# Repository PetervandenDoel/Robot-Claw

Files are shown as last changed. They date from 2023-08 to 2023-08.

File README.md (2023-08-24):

# Robot-Claw

The project demo date was not filmed, the video included is us testing its functionality before the claw was fully assembled. A video of the full project will be uploaded once we can get some of the teammates back together to film a proper demo.  
https://drive.google.com/file/d/1z_p-viNf-aqcb_K7y_1ZdQ1qlZZi11r3/view?usp=sharing

ELEC 391 Claw

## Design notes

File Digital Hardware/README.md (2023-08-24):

The PCB for all the digital hardware. Below the images is an explanation of design choices.











**Decoder and MUX saving GPIOs:** The motor decoder chip that was chosen counts encoder pulses and returns them as a 32 bit value. The decoder requires a clock which is what the crystal oscillator on the PCB is for. The data is accessed across 8 pins with a 2 bit internal multiplexer to iterate through each set of eight bits to retrieve the 32 bit value. With 8 data pins and four pins for interfacing with it, the decoder requires a total of 12 GPIO pins to function. In order to save on GPIO pins a three bit multiplexer was used which complicated the firmware's get_position() routine, but reduced the number of data pins down from 8 to 3 select pins and 1 data input for a total of only 8 GPIO pins needed to read the motor's position.  

**Headers:** This is really the key theme of this PCB so the header types will be discussed individually. All of the all the headers used in this PCB were arduino female headers with clips inside of them similar to this screenshot.



**Level shifter headers:** the headers labelled MUXLS, MISCLS, DECLS, and ANLS are for adafruit level shifters to shift the signals between the 3.3V ESP32 and the 5V multiplexer, ultrasound sensor, decoder, and analog PCB interface respectively. While the ESP 32 can tolerate 5 volts as an input, it cannot output 3.3 volts and it is simply best practice to level shift either way. It proved useful to keep the level shifters and headers because they could be removed to perform tests with breadboard prototypes or use the headers as debug pins and placed back in whenever we wanted. At one point when we did not have an ESP32 available, we simply shorted all of the level shifter headers together with jumpers and ran the board using a 5V Arduino mega.

**ESP32 Headers:** The ESP 32 dev board could be removed and plug back into headers as opposed to having it soldered into the PCB. The ESP 32 would actually refuse to have code flashed on to it when it was plugged into the PCB or our breadboard prototype(probably something to do with where TX and RX pins are connected) so the arduino style headers proved essential. The second set of debug headers directly adjacent also proved to be extremely useful when trying to identify issues with noise and multiplexer signals

There are two other headers one to connect the ultrasonic distance sensor module to the esp, and one that connects to the analog PCB to control the motor and act as a 5V power supply for the digital hardware.

**Silkscreens:** A lot of time was put in to maximally label every pin on every header without violating the PCB manufacturer's silkscreen design rules. Different labels were made different sizes based on the readability of the individual characters at those sizes and thicknesses to preserve space and maximize the amount of labels. These ended up being invaluable for debugging and allowed us, at one point, to use an Arduino mega instead of an ESP32 and connect all the GPIOs to the right pins without much issue.

**Power planes:** A 5V(red) and GND(blue) plane were implemented with the aim of reducing noise, this should have been done differently and will be discussed among potential improvements 

**potential improvements**

**Decoder crosstalk(main issue):** 
**How do we know the issue is crosstalk?** The motor's position value that the ESP32 acquired from the decoder+MUX was quite prone to spiking and some digital low pass filtering had to be implemented to tell the PID controller to ignore junk data. If the encoder signals themselves were having problems, the huge spikes would have been stored in the decoder's internal register, but these spikes were transient and the values always settled back to a reasonable one which suggests bits being flipped because of crosstalk on the lines between the decoder and the multiplexer. 

**Why is there crosstalk?** The traces connecting the decoder and multiplexer are so close that some of them don't even have any ground plane separating them to absorb EMI(picture below). In the getByte() function, the select signals of the multiplexer change around once per microsecond so it's unsurprising that high frequency signals can flip bits on adjacent traces that aren't even shielded from one another, they should have been spaced out more.



**Unused routing space:** A lot of traces are routed very close together despite the fact that there is actually a lot of space on the board that routing could be done through.

**Power planes:** Since this is not a high power circuit, it doesn't make too much sense to have 5V and GND power planes. Instead, it would make more sense to have a ground plane on each layer for noise reduction. 

**Crystal is too large, literally:** A very large thru-hole crystal oscillator was chosen for the motor decoder. Seeing how the crystal just clocks digital hardware inside of the decoder, frequency stability and impedance characteristics aren't very important. It would have been wise to compromise on other characteristics in order to get a smaller crystal. 

**Aesthetics:**
**Non-symmetrical screw holes:** Our professor actually criticized us for this funnily enough. There are two holes for screws on the top of the PCB but not the bottom and the asymmetry is kind of weird.
**Sporadic name placement:** Our names are placed in random spots all over the PCB wherever we could fit them, we don't have one nice little corner that we put all of them in; it could look a lot better.

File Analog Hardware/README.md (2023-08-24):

Pictures have been included and below the pictures there is an explanation of design choices










**Design choices:**

**Power planes:** a ground(blue) and 12 Volt(red) plane were used in order to minimize the impedance between the power supply and components

**power supply** 12V barrel jack will normally supply power, but there is also a 12V GND header which allows for other power supplies to be used besides just the barrel Jack. The 5V GND header proved useful for providing only digital power when trying to debug our design without actually driving the motor and causing our claw to move; it allowed to test our state machine, decoder, and control system while moving the claw by hand.

**Motor Traces:** the PCB traces supplying the motor with power were made very thick in order to minimize resistance

**Headers:** There are two sets of headers, one to connect the analog PCB to the digital PCB and the other one to connect the analog PCB to the motor. for both of them an additional debug header was provided. The motor debug header proved useful for debugging because it allowed us to probe the motor's encoder pulses and power signals. A pure 5V GND and 12V GND header were also included to allow us to supply power to other devices, serve as an additional power source besides the barrel Jack, and hotswap power supply regulation capacitors to see what worked for us.

**PCB shape:** the PCB's edges were clipped in order to avoid having 90 degree edges on our power planes. The PCB was also designed to be compact and small to fit within an internal compartment of the claw

**Motor driver:** A premade H bridge IC with sufficent rated current simplifies the process of driving the motor and allows us to not have to worry about any of the complex timing that goes into designing an H bridge driver to avoid shorts 

**Motor** a JGA25 brshed DC motor was chosen with a built in decoder and 42 to one gearbox to allow for sufficient torque and for the motor shaft to be directly coupled to our claw mechanism without needing to construct a gearbox ourselves

**room for improvement** 

**too much room for caps** the Altium footprints chosen for our power supply regulation capacitors are way too big for what we actually used, some smaller ones would have helped us save space

**analog to digital PCB header** the plastic clip to connect the analog PCB to the digital PCB never ended up being used. It would have been better to have two identical thru-hole headers to allow for debugging the signals that would go from the analog to digital board.

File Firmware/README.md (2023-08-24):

ELEC 391 state

The claw operates as a state machine that will open until a limit switch is hit in order to zero its position, then using an ultrasonic distance sensor it will close when it detects that it is close enough to the ground to pick up an object and once the user carries the claw upwards and then brings it back down above another surface it will drop the object. The claw's position is controlled by driving a motor at a given PWM frequency and direction using a PID control loop triggered at a known control frequency through an interrupt service routine. 

Some firmware design choices

**Filtering: Line 474:** due to bit errors in the signals read from the multiplexers, there are sometimes large spikes in the determined position value. A simple low pass filter is implemented where if the current error differs from the previous error by too large of a number, the previous error is returned. 

**Missed Echos: Line 344:** ultrasound sensor values that are too high are also filtered out because they are assumed to be due to missed echoes

**State machine hysteresis: in every state transition:** I have heard this technique referred to as hysteresis before in some contexts but I'm not sure if that's a proper term. The ultrasonic sensor distance boundaries for transitions between the claw's different states are placed sufficiently far apart enough that rapid transitions when the user has the claw around the border between two states will never happen. 

**get_position modularity: line 113 to 293:** the motor decoder chip outputs a 32 bit value in 8 bit increments determined by select signals fed into the internal multiplexer. Another external multiplexer is used in order to reduce the number of GPIO pins that need to be used to read from the decoder from 8 down to 5. A helper function called getByte was created as a routine to extract one byte of data from the 8 decoder pins by iterating through all the select signals on the external multiplexer. get_position calls getByte 4 times, once for every select signal fed to the decoders internal multiplexer so the total 32 bit value can be acquired

**PID nonlinearities:** due to problems with the static friction of the joints, some nonlinearities were introduced into the PID controller in order to help it behave better. The three PID nonlinearities are listed below and are justified.

**Duty cycle boundries: line 499:** a hard upper and lower limit are placed on the allowable motor driver duty cycles so if the control signal exceeds a certain amount or falls below a certain amount it will be pulled back to within a certain range. Setting a lower bound allows the claw to continue moving as opposed to getting stuck due to static friction when the control signal reduces as the desired position is approached. An upper bound is set because the heavy claws will gain too much momentum if the control signal is allowed to be too high. 

**"settled" condition: line 481:** once the error drops below a certain point the PID loop is told to stop and consider itself to have settled on the correct position as opposed to allowing slight integral error to continue building causing the claw to sharply bounce back and forth. The reason why it sharply bounces back and forth instead of oscillating is because as the control signal slowly builds, the motor slowly starts outputting enough torque to the point where once static friction is overcome the claw will jerk a little bit and then stop again.

**integral error reset:** on every state transition: the integral term for the PID controller is reset every single time a state transition occurs and the new desired position is set. Because the claw moves quite slowly a lot of integral air is build up in the time it takes for the claw to close or open as it does in response to state transitions. This large build of integral error ended up being quite problematic so it was reset to 0 on every state transition

**controlling LED's duty cycle without interrupts: line 442:** in order to avoid any complexities with prioritizing interrupts a single interrupt is used for the PID control loop and controlling the duty cycle of a blinking LED to represent state. Since the LED blinks every 1s the PID loop runs every 0.1s, and the LED duty cycles for the different states differ by increments of 0.1s, an LED counter variable is incremented and modulo operations are used within each state to determine whether the LED should be on or off and this achieves the controlled duty cycle cycle blinking behavior.

**Room for improvement** 

**removing overley cautious multiplexer settle delays** the highly conservative control frequency of 10 Hertz was chosen based on code that gave multiplexer signals excessive amounts of time to settle when acquiring motor position from the decoder. The get_position function has multiple 25ms delays and shortening these delays by orders of magnitude would probably not cause problems and allow for a much faster control frequency and better PID performance.

**Multiple interrupt management**  Since turning an LED on or off is very quick, controlling the LED's duty cycle using another ISR would probably not interrupt our PID controller very much and would have allowed us to have any control frequency we want and any LED duty cycle we want without having to tie the two quantities together in order to use the same interrupt for two tasks.

**separate position acquisition process to allow for increase in control frequency** all of the firmware runs on a single core of the ESP 32, it would be wise to have some tasks like managing the state machine and acquiring the motors's position from the decoder chip running on a separate core from the PID controller and this would allow for a faster control frequency and better performance

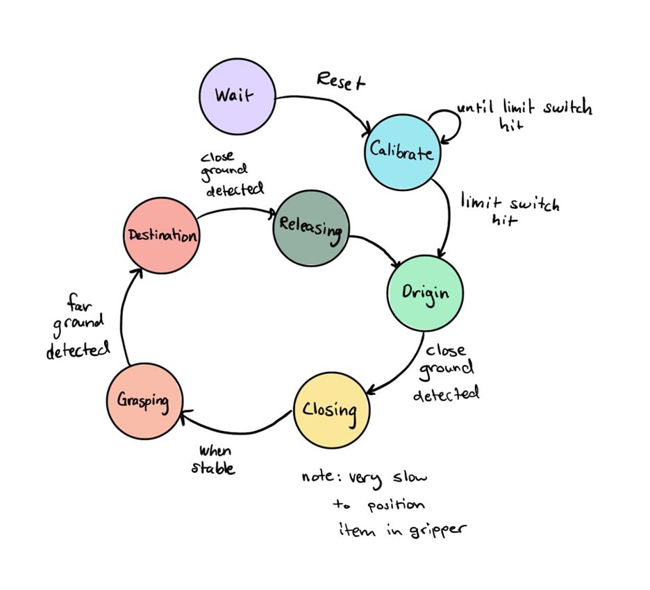
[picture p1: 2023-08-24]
Firmware/ELEC 391 state.png

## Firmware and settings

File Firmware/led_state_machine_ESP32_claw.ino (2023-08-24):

#define LED 32
#define LIMIT_SWITCH 22
#define STOCCO_RESET 12
// defines pins numbers
volatile float desired_position = 0.0;
#define RESET 21
int settled_flag = 0;

const int trigPin = 33;
const int echoPin = 34;
// defines variables
long duration;
int distance;

volatile int LEDcounter=0;

volatile char state[20];
#include <Timer.h>
//#define ENCA 4 //YELLOW
//#define ENCB 2 //WHITE
#define IN1 4  //H-bridge
#define IN2 15  //H-bridge
#define EN 19 //PWM
#define OE 13
#define SEL1 2
#define SEL2 27
#define RST 26
#define A 25
#define B 5
#define C 18
#define MUXIN 35
#include <math.h>


//variables
Timer timer;


//THIS NEEDS TO BE GLOBAL OR VOLATILE ???THIS PREVT VARIABLE 


long prevT = 0;
float eprev = 0;
volatile float eintegral = 0;
//int Flag = 0;
int i;
int byte11[8];
int byte21[8];
int byte31[8];
int byte41[8];
int bytetot[32];
int ppr=0;
volatile long totalcount=0;






void setup() {
  pinMode(trigPin, OUTPUT); // Sets the trigPin as an Output
  pinMode(echoPin, INPUT); // Sets the echoPin as an Input
  pinMode(LED,OUTPUT);
  Serial.begin(115200); // Starts the serial communication
  pinMode(RESET,INPUT); 
  pinMode(LIMIT_SWITCH, INPUT);



  // configure ISR to run every 100 milliseconds
  timer.every(100, timerISR);
  //pinMode(ENCA, INPUT_PULLUP);
  //pinMode(ENCB, INPUT_PULLUP);
  pinMode(EN, OUTPUT);
  pinMode(IN1, OUTPUT);
  pinMode(IN2, OUTPUT);

  //analogWriteFrequency(5000);

  pinMode(OE,OUTPUT);
  pinMode(SEL1,OUTPUT);
  pinMode(SEL2,OUTPUT);
  pinMode(RST,OUTPUT);

  //MULTIPLEXER I/O DEFINITIONS
  pinMode(A,OUTPUT);
  pinMode(B,OUTPUT);
  pinMode(C,OUTPUT);
  pinMode(MUXIN,INPUT);

  pinMode(STOCCO_RESET,INPUT);

 //RESET
 
 reset_decoder();
 /*
  digitalWrite(RST,LOW);
  delayMicroseconds(10);
  digitalWrite(RST,HIGH);
*/
}


void reset_decoder(){
  digitalWrite(RST,LOW);
  delayMicroseconds(10);
  digitalWrite(RST,HIGH);
  
  }

// interfacing with multiplexers on PCB to get one byte of data from decoder pins

byte getByte(){
  byte by1=0;
  byte by2=0;
  while(1){
    
    //read first byte

    digitalWrite(C,LOW);
    digitalWrite(B,LOW);
    digitalWrite(A,LOW);    
    delayMicroseconds(1);
    by1 |= (digitalRead(MUXIN)<<0);
    digitalWrite(C,LOW);
    digitalWrite(B,LOW);
    digitalWrite(A,HIGH);    
    delayMicroseconds(1);
    by1 |= (digitalRead(MUXIN)<<1);
    digitalWrite(C,LOW);
    digitalWrite(B,HIGH);
    digitalWrite(A,LOW); 
    delayMicroseconds(1);   
    by1 |= (digitalRead(MUXIN)<<2);
    digitalWrite(C,LOW);
    digitalWrite(B,HIGH);
    digitalWrite(A,HIGH);
    delayMicroseconds(1);    
    by1 |= (digitalRead(MUXIN)<<3);
    digitalWrite(C,HIGH);
    digitalWrite(B,LOW);
    digitalWrite(A,LOW); 
    delayMicroseconds(1);   
    by1 |= (digitalRead(MUXIN)<<4);
    digitalWrite(C,HIGH);
    digitalWrite(B,LOW);
    digitalWrite(A,HIGH);
    delayMicroseconds(1);    
    by1 |= (digitalRead(MUXIN)<<5);
    digitalWrite(C,HIGH);
    digitalWrite(B,HIGH);
    digitalWrite(A,LOW); 
    delayMicroseconds(1);   
    by1 |= (digitalRead(MUXIN)<<6);
    digitalWrite(C,HIGH);
    digitalWrite(B,HIGH);
    digitalWrite(A,HIGH);
    delayMicroseconds(1);    
    by1 |= (digitalRead(MUXIN)<<7);
      

    //READ BYTE SECOND TIME TO SEE IF ITS STABLE

    digitalWrite(C,LOW);
    digitalWrite(B,LOW);
    digitalWrite(A,LOW);    
    delayMicroseconds(1);
    by2 |= (digitalRead(MUXIN)<<0);
    digitalWrite(C,LOW);
    digitalWrite(B,LOW);
    digitalWrite(A,HIGH);    
    delayMicroseconds(1);
    by2 |= (digitalRead(MUXIN)<<1);
    digitalWrite(C,LOW);
    digitalWrite(B,HIGH);
    digitalWrite(A,LOW); 
    delayMicroseconds(1);   
    by2 |= (digitalRead(MUXIN)<<2);
    digitalWrite(C,LOW);
    digitalWrite(B,HIGH);
    digitalWrite(A,HIGH);
    delayMicroseconds(1);    
    by2 |= (digitalRead(MUXIN)<<3);
    digitalWrite(C,HIGH);
    digitalWrite(B,LOW);
    digitalWrite(A,LOW); 
    delayMicroseconds(1);   
    by2 |= (digitalRead(MUXIN)<<4);
    digitalWrite(C,HIGH);
    digitalWrite(B,LOW);
    digitalWrite(A,HIGH);
    delayMicroseconds(1);    
    by2 |= (digitalRead(MUXIN)<<5);
    digitalWrite(C,HIGH);
    digitalWrite(B,HIGH);
    digitalWrite(A,LOW); 
    delayMicroseconds(1);   
    by2 |= (digitalRead(MUXIN)<<6);
    digitalWrite(C,HIGH);
    digitalWrite(B,HIGH);
    digitalWrite(A,HIGH);
    delayMicroseconds(1);    
    by2 |= (digitalRead(MUXIN)<<7);
      
      
       
    
    //only break loop if equal

    if(by1==by2){
      break;
        }
    
    }
    //we know its stable
    return by1;
  
}


//interfacing with decoder's internal multiplexers to get stored position value from motor decoder
float get_position(){
  byte byte1=0;
  byte byte2=0;
  byte byte3=0;
  byte byte4=0;
  
  //data

  //store in latches

 
 digitalWrite(OE,HIGH);
 delay(25);

  digitalWrite(SEL1,LOW);
  digitalWrite(SEL2,HIGH);
  
 digitalWrite(OE,LOW);
 //now we ready
//-------------------------------------------------Capturing MSB 
  //select byte 1

  //ready to get MSB

  byte1=getByte();
  
//-------------------------------------------------Capturing 2 byte 

  digitalWrite(SEL1,HIGH);
  digitalWrite(SEL2,HIGH);
  //delayMicroseconds(10);    

  
  //ready to get 2nd byte
  byte2=getByte();
  
//-------------------------------------------------Capturing 3 byte 
  digitalWrite(SEL1,LOW);
  digitalWrite(SEL2,LOW);   

  //ready to get 3rd byte
  byte3=getByte();
    
//-------------------------------------------------Capturing 4 byte 
  digitalWrite(SEL1,HIGH);
  digitalWrite(SEL2,LOW);   
  
  //ready to get LSB
  
  byte4=getByte();
 
 digitalWrite(OE,HIGH);
 delay(25);
    //print

long total=0;


//combining bytes with proper place values
total=((long)byte1<<24)|((long)byte2<<16)|((long)byte3<<8)|((long)byte4<<0);

totalcount = total;

float revolutions = 0;

revolutions=(totalcount)/(4.0*34.0*360.0);



Serial.println(revolutions);
return revolutions ;
}


void setMotorPos(int flag, int pwmVal, int pwm, int in1, int in2) {
  
  if (flag == 1) {
    motor_forwards();
  } else if (flag == -1) {
    motor_backwards();
  } else {
    motor_stop();
  }
  
  analogWrite(EN, pwmVal);
}


void motor_forwards() {
  digitalWrite(IN1, HIGH);
  digitalWrite(IN2, LOW);
}

void motor_backwards(){
  digitalWrite(IN1, LOW);
  digitalWrite(IN2, HIGH);
}

void motor_stop(){
  digitalWrite(IN1, LOW);
  digitalWrite(IN2, LOW);
}



//using ultrasonic sensor to get distance from ground
float get_distance(float prev_d) {
  // Clears the trigPin
  digitalWrite(trigPin, LOW);
  delayMicroseconds(2);
  // Sets the trigPin on HIGH state for 10 micro seconds
  digitalWrite(trigPin, HIGH);
  delayMicroseconds(10);
  digitalWrite(trigPin, LOW);
  // Reads the echoPin, returns the sound wave travel time in microseconds
  duration = pulseIn(echoPin, HIGH);
  // Calculating the distance
  distance = duration * 0.034 / 2;
  // Prints the distance on the Serial Monitor
  //Serial.print("Distance: ");
  //Serial.println(distance);

// distance values should never go above 200, this accounts for missed sound reflections on ultrasound sensor
  if(distance>200){ 
    return (float) prev_d;
    }
    //Serial.println( distance);
  return (float)distance;
}


// different states for the robot claw's state machine

void object_origin(){
  desired_position = 0.11;
  timer.update();

  if (LEDcounter %10 == 0){
    digitalWrite(LED,HIGH);
  }
  
  //delay(700);
  if (LEDcounter % 10 == 7){
    digitalWrite(LED,LOW);
  }
  //delay(300);
  Serial.println("object origin");

}
void closing_object(){
  
  desired_position = 0.2;
  timer.update();
  //Serial.print("LED counter is ");
  //Serial.println(LEDcounter);
  if(LEDcounter%10==0){
    digitalWrite(LED, HIGH);
  }
  //delay(100);
  if (LEDcounter % 10 == 1){
    digitalWrite(LED, LOW);
  }
  //delay(900);
  Serial.println("closing");

}

void grasping_object(){
  
  desired_position = 1;
  timer.update();
  //Serial.print("LED counter is ");
  //Serial.println(LEDcounter);
  if(LEDcounter%10==0){
    digitalWrite(LED, HIGH);
  }
  //delay(100);
  if (LEDcounter % 10 == 1){
    digitalWrite(LED, LOW);
  }
  //delay(900);
  Serial.println("grasping");

}

void object_destination(){
  desired_position = 1;
  timer.update();  //MAYBE??????
  if(LEDcounter%10 == 0){
    digitalWrite(LED, HIGH);
  }
  //delay(400);
  if(LEDcounter %10 == 4){
    digitalWrite(LED, LOW);
  }
  //delay(600);
  Serial.println("destination");

}

void releasing_object(){
  desired_position = 0.11;
  timer.update();
  
  digitalWrite(LED, HIGH);
  //delay(1000);
  Serial.println("releasing");

}


// PID control loop that is triggered by a timer ISR at the control frequency
void timerISR()
{
 
    
    //delay(1);

    // this LED counter variable uses the control frequency to control the duty cycle of a blinking LED without having to use another one of the arduino IDE's limited configurable 
    //interrupts
    LEDcounter++;
    
    float pos = get_position();

    //PID constants
    float kp = 1050;
    float kd = 100;
    //float kd=0.0;
    float ki = 2.8;
    int start_time = micros();
    settled_flag = 0;

    //time difference
    //long currT = micros();
    //long et = currT - prevT;
    float deltaT = 10;
    //float deltaT = ((float)(currT - prevT))/1.0E4;
//    Serial.print("CurrT: ");
//    Serial.println(currT);
//    Serial.print("PRevT is: ");
//    Serial.println(prevT);
//    Serial.print("delta T value: ");
//    Serial.println(deltaT);
//    prevT = currT;
    //Serial.print("Calculation time difference");
    //Serial.println(micros()-start_time);
 

    //error
    start_time = micros();
    float e = pos - desired_position;

    // digital low pass filtering, since position is in units of revolutions, 1/20 revolutions would correspond to a change in error of 53
    // 1/20 revolutions in the control period of 0.1s corresponds to a speed of 0.5 RPS which is far faster than our motor should ever run
    if((e-eprev)>53 || (e-eprev)<-53){
      e=eprev;
    }
   
    //this is to determine whether or not the PID loop has settled
    if (fabs(e) > 0.016) {
    //finite difference derivative
    float dedt = (e - eprev)/deltaT;

    //integral
    eintegral = eintegral + e*deltaT;

    //control signal
    float u = kp*e + kd*dedt + ki*eintegral;

    //motor power
    float pwr = fabs(u);
    //Serial.print("Error calculation time");
   // Serial.println(micros()-start_time);

    start_time = micros();

    //Locking our duty cycle between 60 and 220
    if (pwr > 220) {
      pwr = 220;    } 
    if (pwr<60){
      pwr=60;
      }

    //motor direction
    int dir = 1;
    if (u < 0) {
      dir = -1;
    }
    
    //signal the motor
    setMotorPos(dir, pwr, EN, IN1, IN2);

    //store previous error
    eprev = e;


    // lots of debug print statements
    Serial.print("Desired position is: ");
    Serial.println(desired_position);
    Serial.print(" ");
    Serial.print("position is: ");
    Serial.println(pos);
    Serial.print(" ");
    Serial.print("Power motor is getting: ");
    Serial.println(pwr);
    Serial.print("error is ");
    Serial.println(e);
    Serial.print("proportional contiburtion ");
    Serial.println(kp*e);
    Serial.print("derivitave contributoin ");
    Serial.println(kd*dedt);
    Serial.print("integral contribution ");
    Serial.println(ki*eintegral);
    Serial.print("control signal is ");
    Serial.println(u);

//    Serial.print("Rest of program");
//    Serial.println(micros()-start_time);
   
    }
    else{
      settled_flag = 1;
    }
    Serial.print("settled flag is: ");
    Serial.println(settled_flag);
}




//State machine based on distance sensor

void loop() {
  float d=70;
  d=get_distance(d);

  Serial.println(distance);

  while(1){
    Serial.println("waitng for stocco");
//    this is for stocco pressing the reset button on his computer
    if(digitalRead(STOCCO_RESET)==1){
      break;
      
      }
  }

  while(1){               //this is for the calibration state, move until limit switch is hit
    
    analogWrite(EN,150);
    //150/255 duty cycle

    motor_forwards();
     d = get_distance(d);
     Serial.println(d);
     Serial.print("Eintegral is: ");
     Serial.println(eintegral);

    if (digitalRead(LIMIT_SWITCH)){
      // making sure limit switch has been pressed for some time
      delay(10);
      if (digitalRead(LIMIT_SWITCH)){
        Serial.println("stopping motor");
        motor_stop();
        reset_decoder();
        Serial.println("decoder reset");
        //delay(1000);
        break;
      }
    }
  }
  eintegral=0.0;
       Serial.print("Eintegral is: ");
     Serial.println(eintegral);

  //label for gotostatement
  open:
  while(1){
    d = get_distance(d);
    Serial.println(d);
    //eintegral = 0;
    Serial.print("Eintegral is: ");
    Serial.println(eintegral);
    

    if (d > 20){
      
      object_origin();
    }
    else break;
  }

  Serial.println("ready to start closing");
  delay(5000);
  //reset integral for new PID target
  eintegral=0.0;
  
  while(1){
    d = get_distance(d);
    Serial.println(d);
    closing_object();
    if (settled_flag == 1){
      delay(500);
      break; 
    }
  }

Serial.println(5);
delay(1000);
for(int index=1;index<5;index++){
    Serial.println(5-index);
    delay(1000);
}
//reset integral for new PID target
eintegral=0.0;  
  
  while(1){
    d = get_distance(d);
      //Serial.println(d);
    if (d < 70){ //this is holding the object on the ground
      grasping_object();
    }
    else break;
  }
  
  while(1){
    d = get_distance(d);
          Serial.println(d);
    if (d > 20){ //this is holding it in the air
      object_destination();
    }
    else break;
  }

//reset integral for new PID target
eintegral=0.0;
  
  while(1){
    d = get_distance(d);
          Serial.println(d);
    if (d < 70){ //ready to release on the ground
      releasing_object();
    }
    else{
      
    goto open;
    break;
    }
  }



  
}
